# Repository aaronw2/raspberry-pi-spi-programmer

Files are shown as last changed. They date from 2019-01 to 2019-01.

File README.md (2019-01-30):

Note that there are some issues with this programmer. I suggest moving to
raspberry-pi-spi-programmer2 instead.  No more development will happen for
this.

SOIC-8 and SOIC-16 SPI Flash Programmer for Raspberry PI

This hat allows the Raspberry PI to program both SOIC-8 and SOIC-16 SPI
NOR devices at 1.8 and 3.3 volts.  The programmer can be enabled either
from SW1 or via GPIO 22. If using GPIO 22 then leave the SW1 in the
Enabled position. LED D1 will light up when the programmer is enabled.
Make sure that the programmer is disabled when inserting or removing
SPI devices.

SW2 allows either 1.8 or 3.3 volts to be used for programming. Make sure
that the programmer is disabled before selecting the appropriate voltage.
A future version of this board may allow this to be set by GPIO pins
as well.

All resistors, capacitors and the LED are 0603 devices.  For capacitors,
use X7R and the higher the voltage the better.  The LED should be capable
of handling 7ma of current.  The recommendation is to use a red LED.

The serial port support is optional.
Additionally, if only SOIC-8 or SOIC-16 devices are to be programmed, the
other socket does not need to be stuffed.

All parts can be found at https://digikey.com

=========== Using ==============

Do not install SPI NOR flash devices in both sockets at the same time.  A
future version of this board may support devices in both sockets.

1. Make sure that the programmer is disabled and that the LED is off.
2. Select the proper voltage for the SPI NOR
3. Install the SPI NOR chip with pin 1 in the lower-left corner away from
   the hinge on the socket.
4. Close the socket.
5. Enable the programmer
6. Run the SPI NOR programming software
7. Disable the programmer
8. The flash chip can be safely removed.

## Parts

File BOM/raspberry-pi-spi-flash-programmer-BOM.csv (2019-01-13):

Refs | Value | Footprint | Quantity | MFR | MPN | SPR | SPN
U2 | AT25SF081-SSHD-X | Aaron:208-7391-55-1902 | 1 | 3M | 208-7391-55-1902 | Digikey | 3M5054-ND
U1 | MX25L25735 | Aaron:216-7224-55-1902 | 1 | 3M | 216-7383-55-1902 | Digikey | 3M5078-ND
SW2;SW1 | SW_SPDT | Aaron:SW_STDP_CF-LD-1DC | 2 | Nidec Copal Electronics | CF-LD-1DC-AW2W | Digikey | 563-1944-ND
C1;C2;C4;C5;C3;C6;C7;C9;C8 | 0.1uF | Capacitor_SMD:C_0603_1608Metric | 9 | - | - | - | -
C10;C12;C11 | 4.7uF | Capacitor_SMD:C_0603_1608Metric | 3 | - | - | - | -
P1 | CONN_13X2 | Connector_PinHeader_2.54mm:PinHeader_2x13_P2.54mm_Vertical | 1 | - | - | - | -
J1 | RJ45 | Connector_RJ:RJ45_Amphenol_54602-x08_Horizontal | 1 | Amphenol | 54602-908LF | Digikey | 609-1046-ND
FID1;FID2 | FIDUCIAL_1MM | Fiducial:Fiducial_Modern_CopperTop | 2 | - | - | - | -
D1 | LED | LED_SMD:LED_0603_1608Metric | 1 | - | - | - | -
U5 | MIC5355-SGYMME | Package_SO:MSOP-8-1EP_3x3mm_P0.65mm_EP2.54x2.8mm_ThermalVias | 1 | Microchip | MIC5355-SGYMME | Digikey | 576-3882-5-ND
U4 | TXB0104D | Package_SO:SOIC-14_3.9x8.7mm_P1.27mm | 1 | - | - | - | -
U3 | MAX3232 | Package_SO:TSSOP-16_4.4x5mm_P0.65mm | 1 | Texas Instruments | MAX3232ECPWR | Digikey | 296-19263-1-ND
Q1 | BSS138 | Package_TO_SOT_SMD:SOT-23 | 1 | ON Semiconductor | BSS138K | Digikey | BSS138KCT-ND
R4;R1;R3;R2;R5;R7 | 4.75K | Resistor_SMD:R_0603_1608Metric | 6 | - | - | - | -
R6 | 560 | Resistor_SMD:R_0603_1608Metric | 1 | - | - | - | -

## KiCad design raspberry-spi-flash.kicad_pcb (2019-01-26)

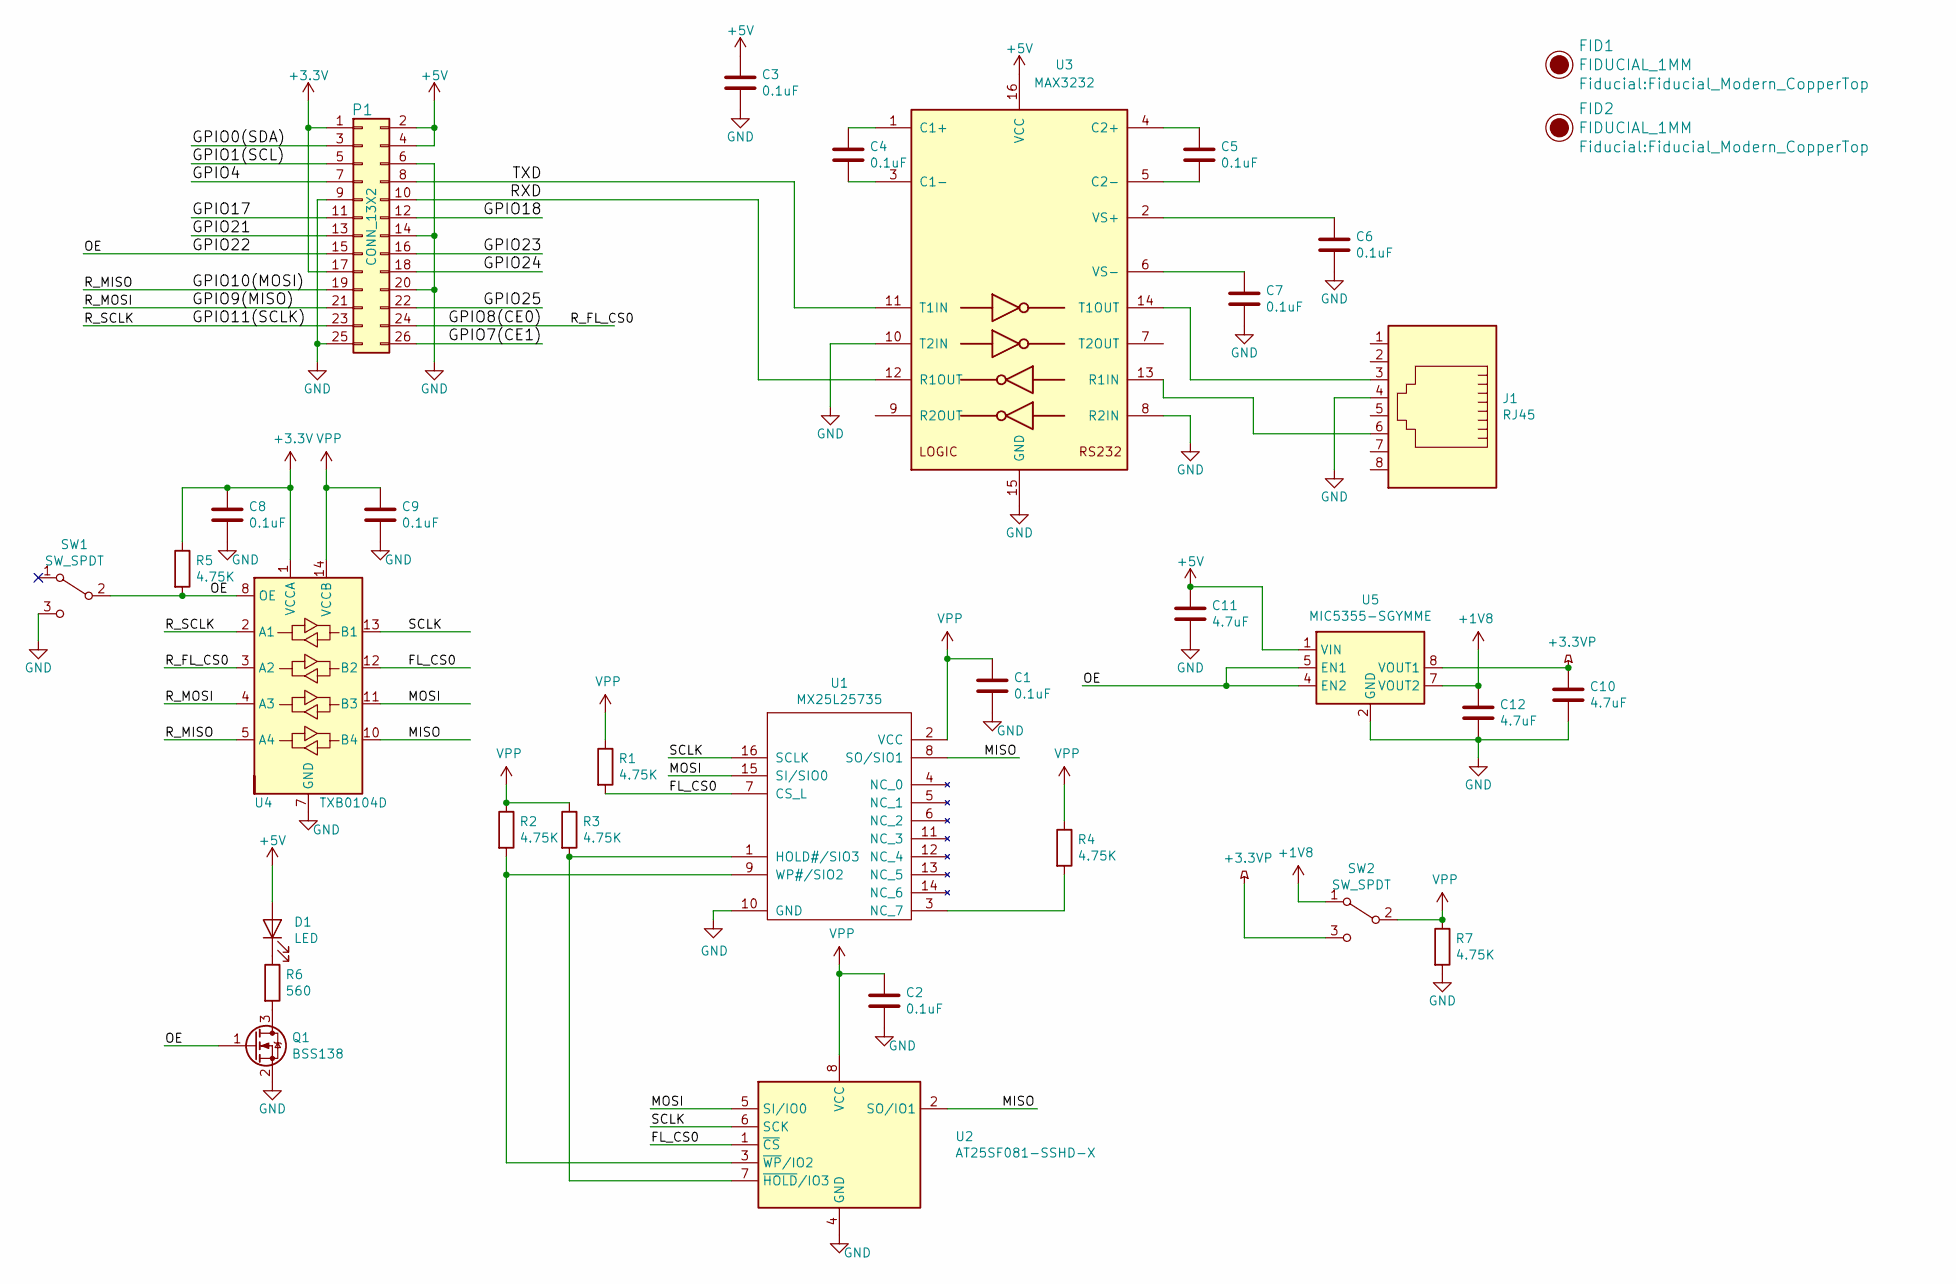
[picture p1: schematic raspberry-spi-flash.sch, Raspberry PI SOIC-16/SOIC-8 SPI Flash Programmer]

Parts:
C1, C2, C3, C4, C5, C6, C7, C8, C9: 0.1uF; C_0603_1608Metric
C10, C11: 4.7uF; C_0603_1608Metric
C12: 4.7uF; C_0603_1608Metric; MPN GRM188R61E475KE15D
D1: LED; LED_0603_1608Metric
FID1, FID2: FIDUCIAL_1MM; Fiducial_Modern_CopperTop
J1: RJ45; RJ45_Amphenol_54602-x08_Horizontal; MPN 54602-908LF
P1: CONN_13X2; PinHeader_2x13_P2.54mm_Vertical
Q1: BSS138; SOT-23; MPN BSS138K
R1, R2, R3, R4, R5, R7: 4.75K; R_0603_1608Metric
R6: 560; R_0603_1608Metric
SW1, SW2: SW_SPDT; SW_STDP_CF-LD-1DC; MPN CF-LD-1DC-AW2W
U1: MX25L25735; 216-7224-55-1902; MPN 216-7383-55-1902
U2: AT25SF081-SSHD-X; 208-7391-55-1902; MPN 208-7391-55-1902
U3: MAX3232; TSSOP-16_4.4x5mm_P0.65mm; MPN MAX3232ECPWR
U4: TXB0104D; SOIC-14_3.9x8.7mm_P1.27mm
U5: MIC5355-SGYMME; MSOP-8-1EP_3x3mm_P0.65mm_EP2.54x2.8mm_ThermalVias; MPN MIC5355-SGYMME

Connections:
+1V8: C12.1, SW2.1 (A), U5.7 (VOUT2)
+3.3VP: C10.1, SW2.3 (C), U5.8 (VOUT1)
+3V3: C8.1, P1.1, P1.17, R5.1, U4.1 (VCCA)
+5V: C3.1, C11.1, D1.2 (A), P1.2, P1.4, U3.16 (VCC), U5.1 (VIN)
/FL_CS0: R1.2, U1.7 (CS_L), U2.1 (~CS), U4.12 (B2)
/GPIO0(SDA): P1.3
/GPIO1(SCL): P1.5
/GPIO4: P1.7
/GPIO7(CE1): P1.26
/GPIO8(CE0): P1.24, U4.3 (A2)
/GPIO9(MISO): P1.21, U4.4 (A3)
/GPIO10(MOSI): P1.19, U4.5 (A4)
/GPIO11(SCLK): P1.23, U4.2 (A1)
/GPIO17: P1.11
/GPIO18: P1.12
/GPIO21: P1.13
/GPIO22: P1.15, Q1.1 (G), R5.2, SW1.2 (B), U4.8 (OE), U5.4 (EN2), U5.5 (EN1)
/GPIO23: P1.16
/GPIO24: P1.18
/GPIO25: P1.22
/MISO: U1.8 (SO/SIO1), U2.2 (SO/IO1), U4.10 (B4)
/MOSI: U1.15 (SI/SIO0), U2.5 (SI/IO0), U4.11 (B3)
/RXD: P1.10, U3.12 (R1OUT)
/SCLK: U1.16 (SCLK), U2.6 (SCK), U4.13 (B1)
/TXD: P1.8, U3.11 (T1IN)
GND: C1.2, C2.2, C3.2, C6.2, C7.2, C8.2, C9.2, C10.2, C11.2, C12.2, J1.4, P1.6, P1.9, P1.14, P1.20, P1.25, Q1.2 (S), R7.2, SW1.3 (C), U1.10 (GND), U2.4 (GND), U3.8 (R2IN), U3.10 (T2IN), U3.15 (GND), U4.7 (GND), U5.2 (GND), U5.9 (GND)
unnamed: C4.1, U3.1 (C1+)
unnamed: C4.2, U3.3 (C1-)
unnamed: C5.1, U3.4 (C2+)
unnamed: C5.2, U3.5 (C2-)
unnamed: C6.1, U3.2 (VS+)
unnamed: C7.1, U3.6 (VS-)
unnamed: D1.1 (K), R6.1
unnamed: J1.3, U3.14 (T1OUT)
unnamed: J1.6, U3.13 (R1IN)
unnamed: Q1.3 (D), R6.2
unnamed: R2.2, U1.9 (WP#/SIO2), U2.3 (~WP~/IO2)
unnamed: R3.2, U1.1 (HOLD#/SIO3), U2.7 (~HOLD~/IO3)
unnamed: R4.2, U1.3 (NC_7)
VPP: C1.1, C2.1, C9.1, R1.1, R2.1, R3.1, R4.1, R7.1, SW2.2 (B), U1.2 (VCC), U2.8 (VCC), U4.14 (VCCB)

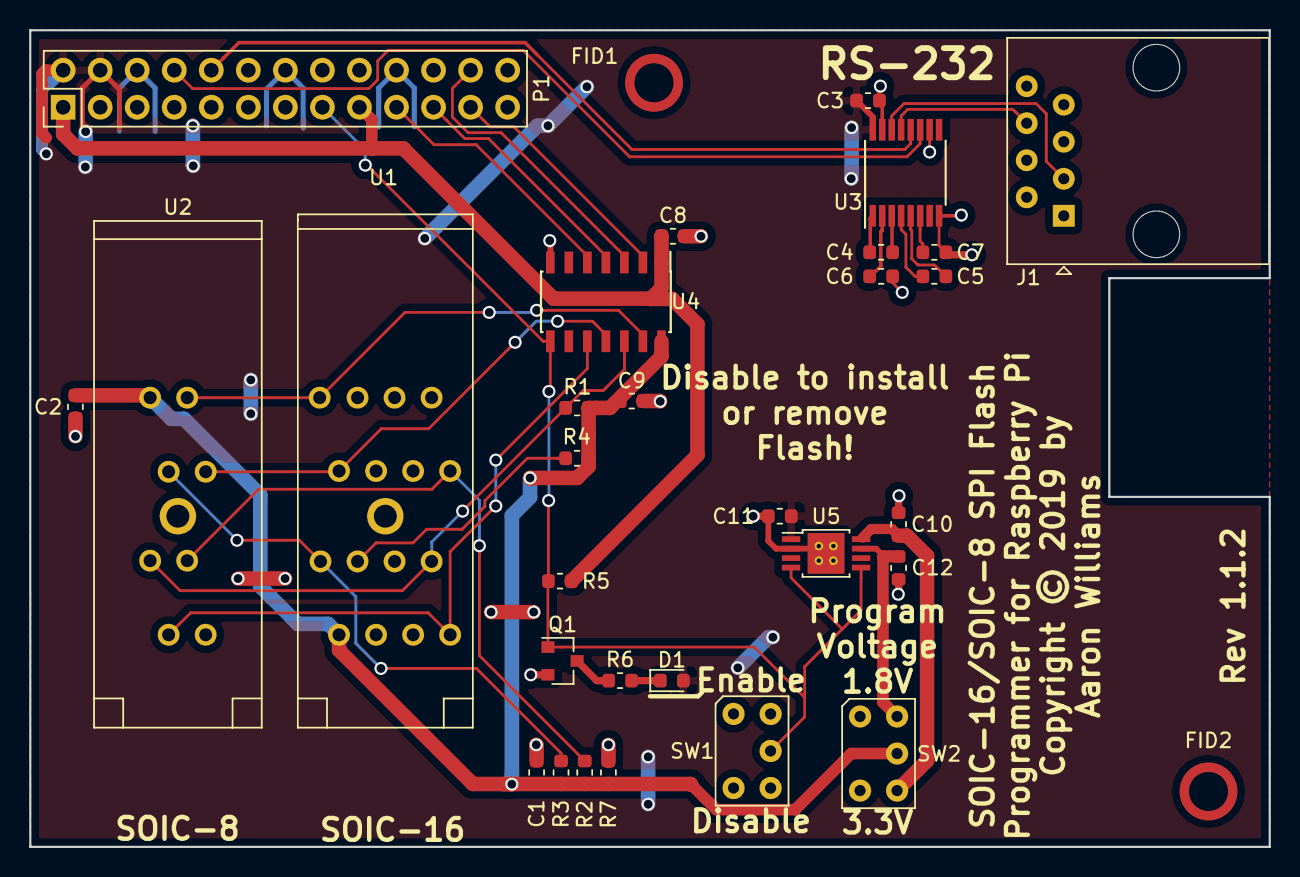
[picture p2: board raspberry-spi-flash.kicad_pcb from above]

Board: 2 copper layers, 85.0 x 56.0 mm, 32 parts (0 on the bottom side), 30 nets.

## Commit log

2019-01-13 Initial commit, revision 1.1
    [raspberry-pi-spi-flash-programmer-BOM.csv, raspberry-spi-flash.kicad_pcb, raspberry-spi-flash.sch]
2019-01-16 Fixed typo
    [raspberry-spi-flash.kicad_pcb]
2019-01-26 Fixed solder mask clearance.
    [raspberry-spi-flash.kicad_pcb]
2019-01-26 Fixed footprint for soic-16 socket.
    [raspberry-spi-flash.kicad_pcb]

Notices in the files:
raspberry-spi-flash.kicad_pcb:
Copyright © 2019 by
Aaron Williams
